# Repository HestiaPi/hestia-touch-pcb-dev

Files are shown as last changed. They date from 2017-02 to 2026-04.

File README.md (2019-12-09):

# HestiaPi Touch

HestiaPi Touch

HestiaPi Touch is a completely open source smart thermostat for your home. With it, you can monitor your home’s temperature, relative humidity, and atmospheric pressure. You can also control your heating, ventilation, air conditioning, hot water, and more from anywhere you have an Internet connection. 

You can do all this securely and with confidence your private data stays private. 

HestiaPi Touch is compatible with many devices and home automation systems and can serve as a central point of control that ties them all together in your home.

For **HestiaPi Touch ONE** select the "ONE" folder above.

# Useful links

* [Main website](https://hestiapi.com/)
* [Documentation & Getting Started Guides](https://github.com/HestiaPi/hestia-touch-openhab/wiki)
* [Community forum](https://community.hestiapi.com/)
* [Code](https://github.com/HestiaPi/hestia-touch-openhab)
* [Electronics (this repo)](https://github.com/HestiaPi/hestia-touch-pcb-dev)
* [3D Case](https://github.com/HestiaPi/hestia-touch-case)

# Support us

HestiaPi is and will always be open source and open hardware. 

Please consider supporting us through our [crowdfunding campaign](https://www.crowdsupply.com/makeopenstuff/hestiapi-touch).

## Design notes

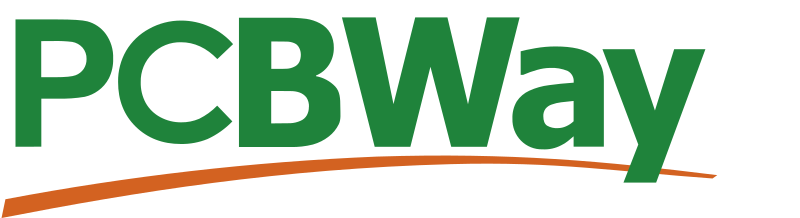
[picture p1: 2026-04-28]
HestiaPi-ONE/KiCAD/PCBWay.bmp

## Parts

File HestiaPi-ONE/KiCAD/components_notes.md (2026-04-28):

# General Notes

- The prices listed here do not include tax nor shipping
- The prices are a snapshot in time. The prices will change over time
- Use alternative components at our own risk. They might work, they might not
- Approximate total cost of for one complete unit (3 relays, US power supply)
  - Components (excluding tax + shipping): $179
  - Tax (varies by jursidiction): $18
  - Shipping: $20
  - Doesn't include a 3D printed case or the solder you'll need to assemble it
  - You'll have parts left over as some are one available in a pack
- Ordering in bulk saves a lot of money (per unit)
  - One project member does this and makes them availalbe for sale
  - https://www.tindie.com/stores/eternalsunshine/

# Switch

- PB400EEQX 3A, 30V DC
  - https://www.mouser.com/ProductDetail/E-Switch/PB400EEQX?qs=f9yNj16SXrL0W%252BH3qwHSkQ%3D%3D
  - https://www.mouser.com/datasheet/2/140/PB400EEQX-3455649.pdf
  - 11mm stem, 11mm body, 2.9mm further to the center of the rear pins
  - $2.10

# Solid state relays

- Panasonic AQG22205
- https://www.mouser.com/ProductDetail/Panasonic-Industrial-Devices/AQG22205?qs=g5ciJ0jwZaGg6SiKVpMkMA%3D%3D
- $4.29

# EU power supply

- HiLink HLK-PM01
- https://www.amazon.com/HLK-PM01-Step-Down-Supply-Intelligent-Household/dp/B01B7GGL6C
- $33.26

# Terminal block

- CUI Devices TB001-500-07BE
- https://www.mouser.com/ProductDetail/490-TB001-500-07BE
- $0.92

# US power supply

- AC 24V to DC 5V buck regulator, 3A or higher
- https://www.amazon.com/gp/product/B07TLL6SN2/?th=1
- $13.31

# 2x20 header pins

- Not needed if you bought a Raspberry Pi with headers pre-installed
- 2x20 headers, 2.54mm pitch
- https://www.mouser.com/ProductDetail/Molex/90131-0140?qs=kEwmkoUtv7QGI7QFyJKDFA%3D%3D
- $3.16

# 2x20 header socket

- 2x20 header socket, 2.54mm picth
- https://www.mouser.com/ProductDetail/Samtec/SSQ-120-01-L-D?qs=%252BZP6%2F%252BtExtDg5xp9qJK50A%3D%3D
- $5.24

# Right angle headers

- https://www.mouser.com/ProductDetail/649-75867-105LF
- https://cdn.amphenol-cs.com/media/wysiwyg/files/documentation/datasheet/boardwiretoboard/bwb_quickie.pdf
- $2.38

Previous pick; it works, but not as well:

- https://www.mouser.com/ProductDetail/Samtec/MTSW-113-07-T-D-100-RA?qs=rU5fayqh%252BE1VVwFKmkPK1g%3D%3D
- https://www.mouser.com/datasheet/2/527/mtsw-2854606.pdf
- $1.61

# Ribbon cable

- https://www.mouser.com/ProductDetail/Samtec/HCMD-13-T-04.00-02-T-G?qs=0lQeLiL1qyYA3A%252BwV50O3A%3D%3D
- https://www.mouser.com/datasheet/2/527/hcmd-2498159.pdf
- $11.93

# LCD touchscreen

- 3.5" touchscreen with XPT2046 touch chip
- https://smile.amazon.com/gp/product/B0BJDTL9J3/
- $17.99

# Temperature & humidity sensor

- BME-280 sensor with breakout board
- https://www.mouser.com/ProductDetail/SparkFun/SEN-13905?qs=t7xnP681wgXFsb5cPFh6iw%3D%3D
- $22.50

# Temp sensor wire

- 4-pin wire with 1x4 header socket connectos
- https://smile.amazon.com/dp/B0789F523N
- $7.99 (that's the price for a 10 pack)

# PCB

- Fabricated by a vendor of your choice
- [OSH Park](https://oshpark.com/) allows ordering just 3 boards, most others have a minimum of 5+
- $50.10 (that's the price for 3 boards, which is the minimum)

# SD Card

- Nearly any micro SD card should do, the 16GB ones seem to be cheapest right now
- $8

# Raspberry Pi Zero 2

- https://www.mouser.com/ProductDetail/Raspberry-Pi/SC0020?qs=rQFj71Wb1eUf2LwSpZJWqw%3D%3D
- $15

# Nuts & bolts

- M2.5 nuts and M2.5x8mm bolts
- https://www.mcmaster.com/90592A006/
  - 1.50 (pack of 100)
- https://www.mcmaster.com/92000A105/
  - $5.17 (pack of 100)

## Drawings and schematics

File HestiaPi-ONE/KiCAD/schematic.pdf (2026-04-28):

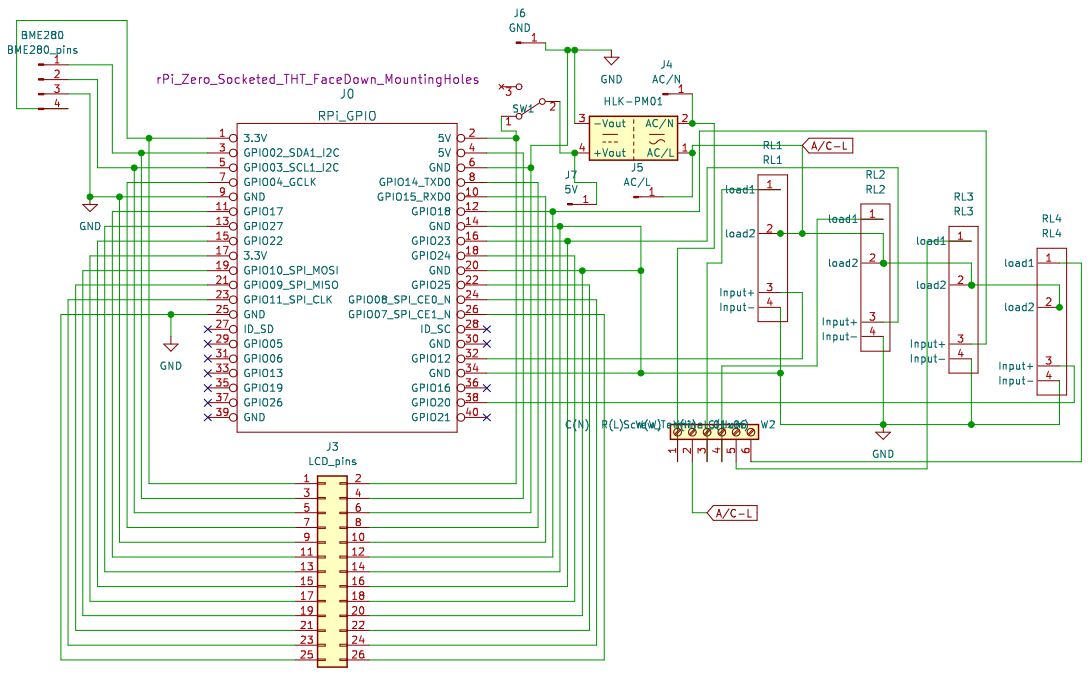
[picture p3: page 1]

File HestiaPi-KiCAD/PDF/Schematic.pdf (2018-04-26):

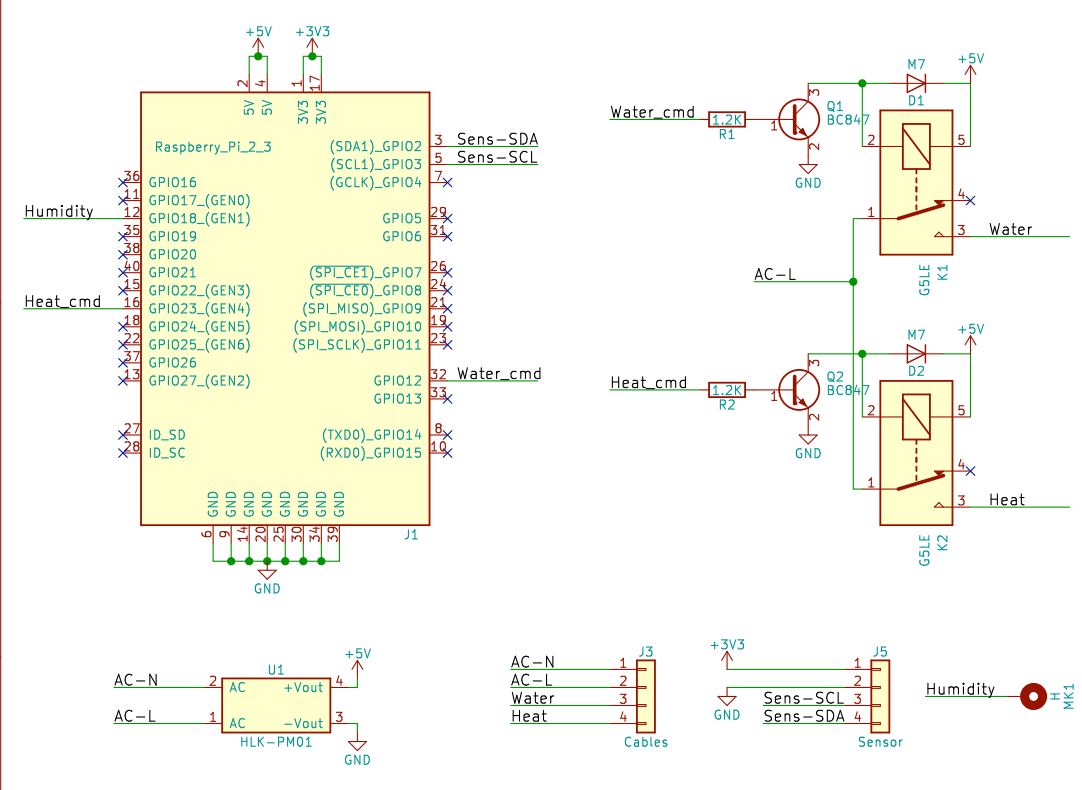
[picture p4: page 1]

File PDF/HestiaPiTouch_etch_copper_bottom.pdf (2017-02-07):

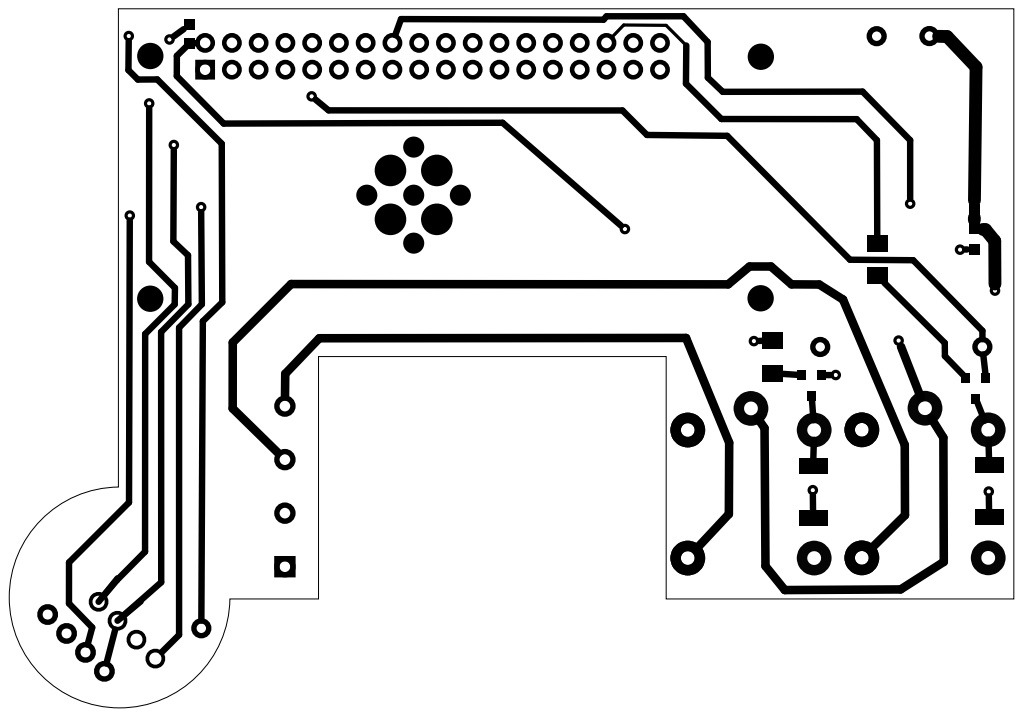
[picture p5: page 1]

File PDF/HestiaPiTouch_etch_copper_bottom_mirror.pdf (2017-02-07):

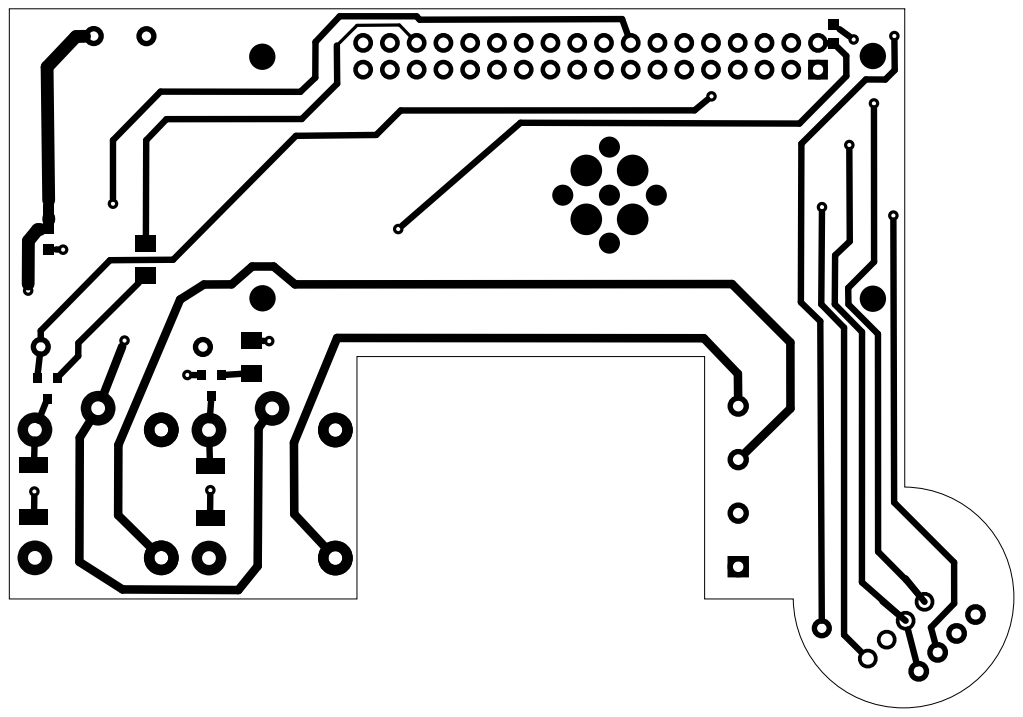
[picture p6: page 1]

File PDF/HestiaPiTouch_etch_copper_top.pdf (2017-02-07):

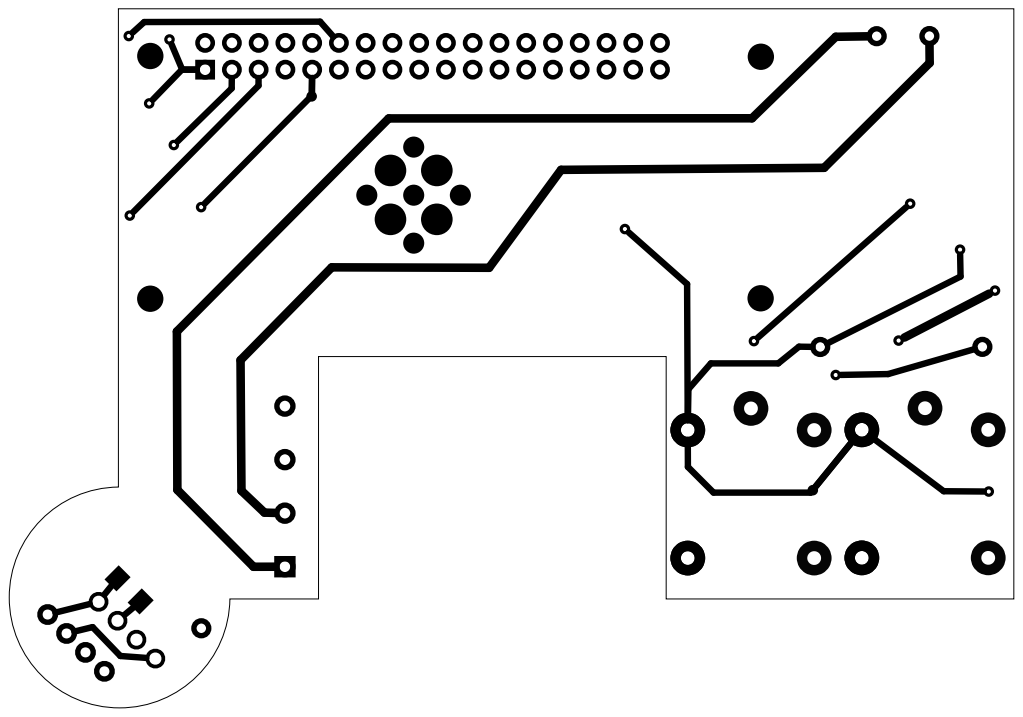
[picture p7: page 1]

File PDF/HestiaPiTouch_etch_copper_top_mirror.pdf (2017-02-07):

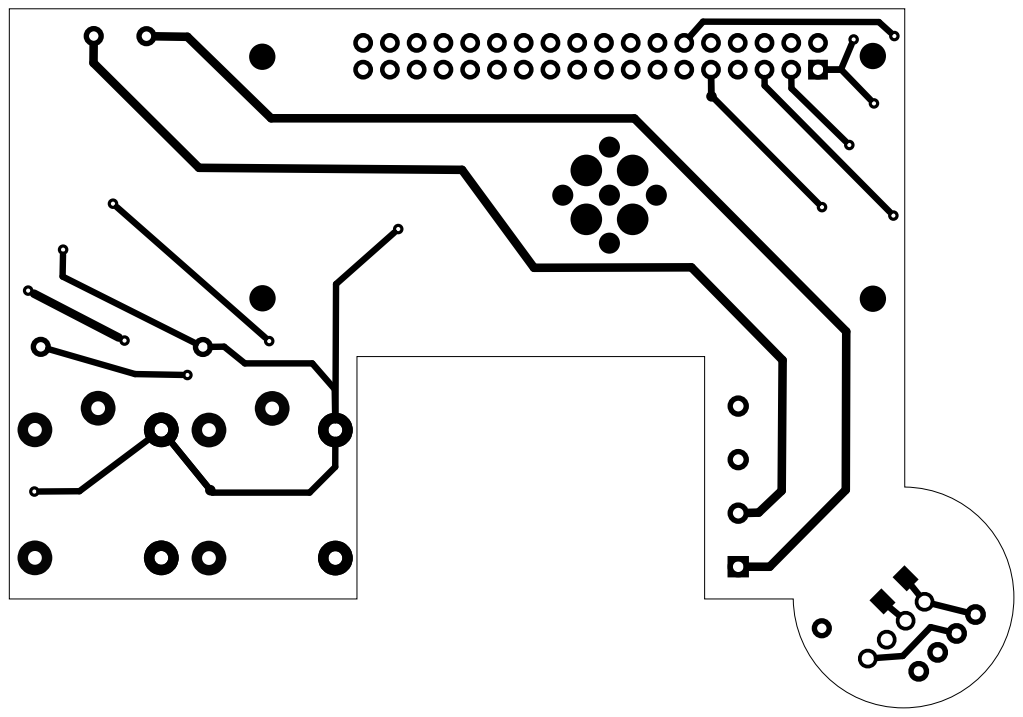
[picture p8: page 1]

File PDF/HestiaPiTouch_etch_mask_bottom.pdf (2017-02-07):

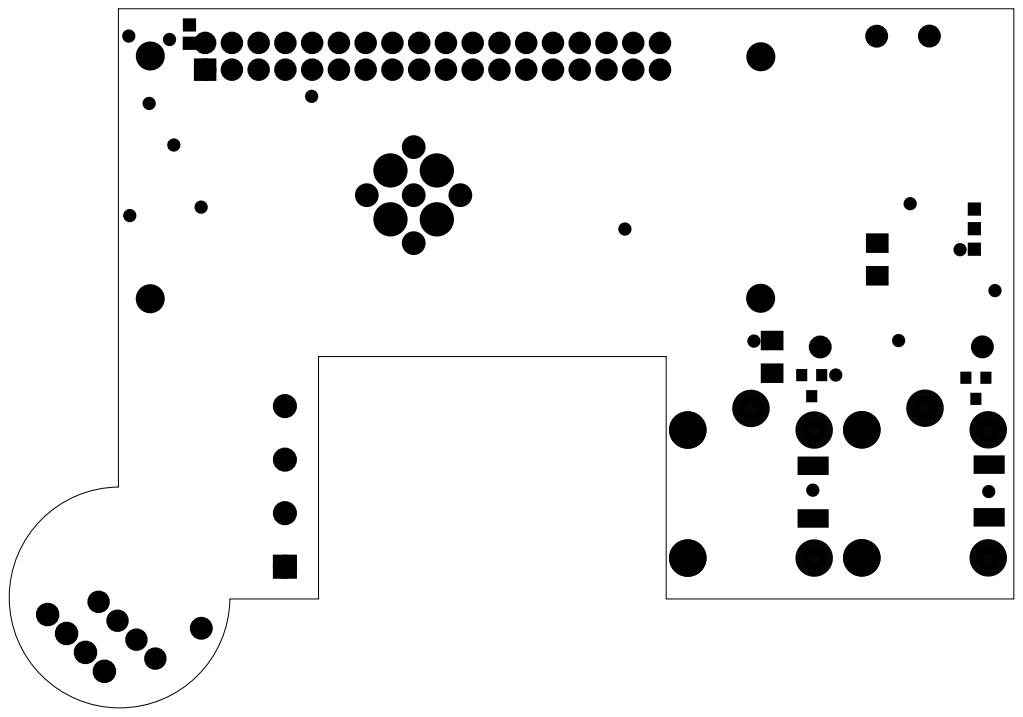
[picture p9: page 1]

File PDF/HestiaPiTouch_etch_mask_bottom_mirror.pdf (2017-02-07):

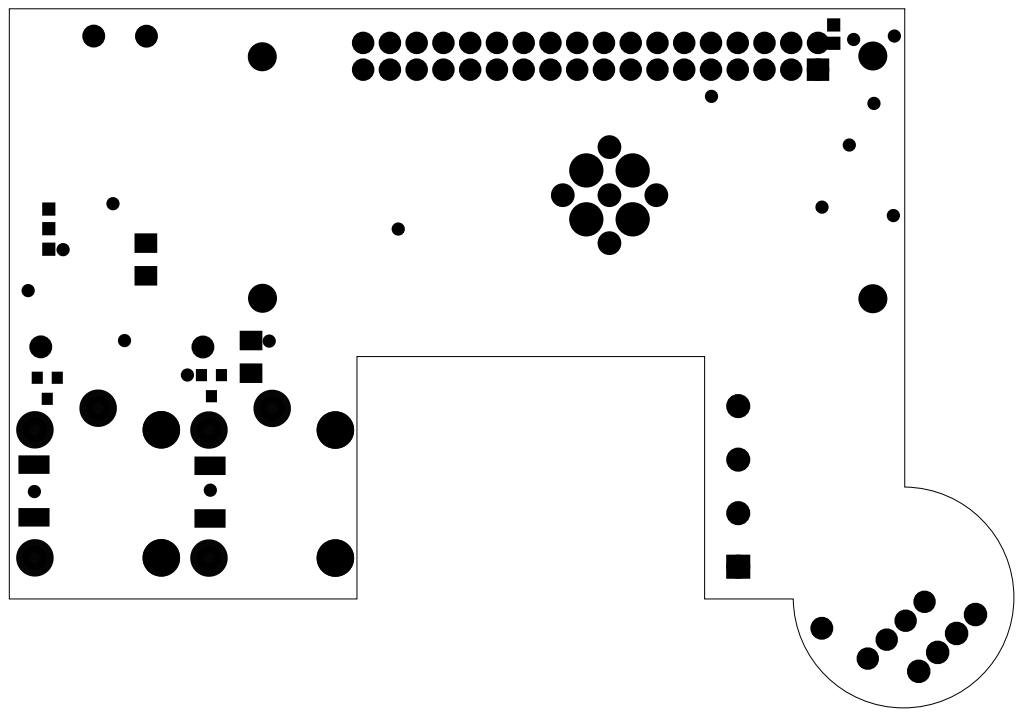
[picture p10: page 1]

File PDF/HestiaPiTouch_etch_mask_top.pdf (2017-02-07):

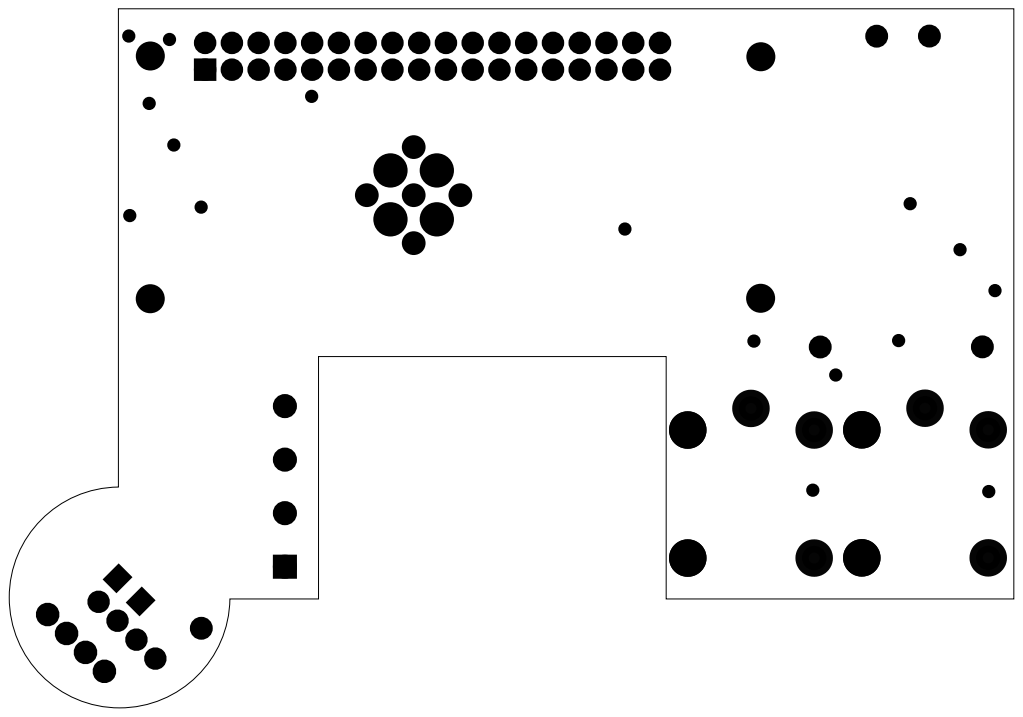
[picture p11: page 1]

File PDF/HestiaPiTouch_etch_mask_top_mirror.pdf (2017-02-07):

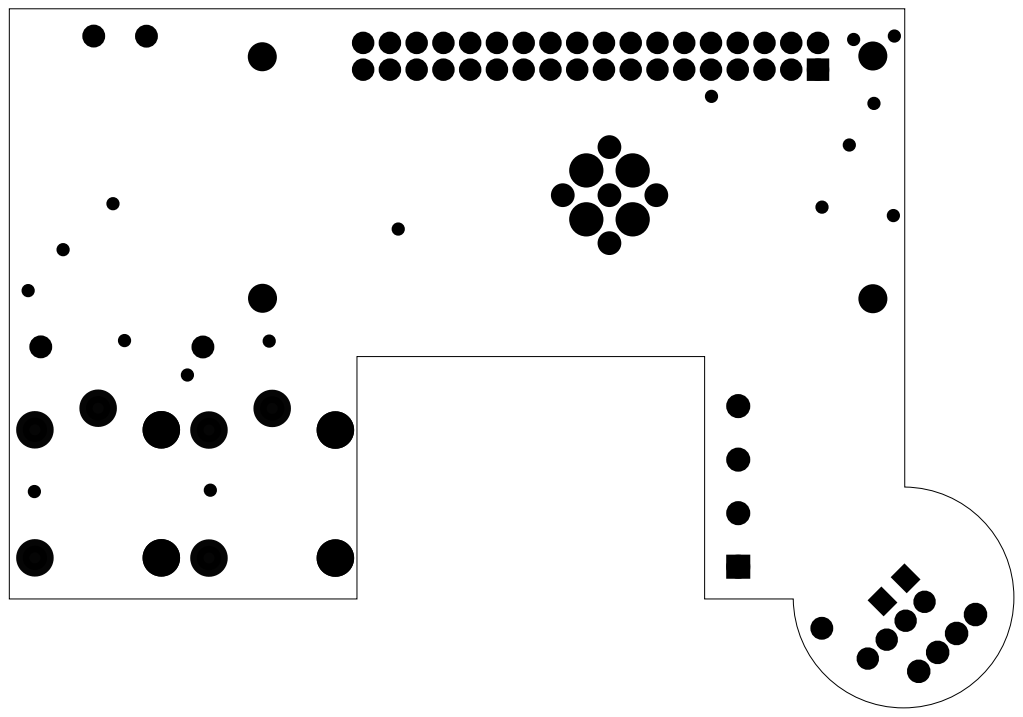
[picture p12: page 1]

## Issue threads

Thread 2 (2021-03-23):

Board outline file for One circuit board

sorvis, 2021-03-23:
Hello,

I tried uploading the Gerbal zip for the One board to oshpark, but it complains "I can't find a board outline file. "

https://oshpark.com/uploads/Jsue3I1o

Would it be possible to add that missing file or perhaps the kicad project? I noticed that the kicad project file works with their software for the other board.

Thank you

gulliverrr, 2021-03-23:
This is not done via KiCAD. I think Fritzing names ones of the needed layers with a different extension.
My suggestion would be to download the zip file, extract it, rename ONE_contour.gml to ONE_contour.GKO (or ONE_contour.gko), re-zip it and try uploading again.
Please report here if it worked

sorvis, 2021-03-23:
Thank you for the quick reply @gulliverrr  I renamed it to ONE_contour.GKO  and it did work just fine!

gulliverrr, 2021-03-23:
Just to mention... I think this difference of Fritzing is not blocking all PCB houses. Some don't complain and process the zip file fine. Since that repository commit, we have moved far from Fritzing as this was our first beginner tool that got us into PCB design.
Glad you got it working

sorvis, 2021-03-23:
Curious if that's an older file that you all created are the newer files in another repository? It looks like the ONE folder was the most recent in this repro.

gulliverrr, 2021-03-24:
No, that would be the latest `released` version. As this project is always progressing, yes there are modifications pending to be either tested or accompanied by the rest of the code, casing, electronics and/or documentation. You are using the right file, for now.

Closed 2021-03-23.

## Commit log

2018-02-10 Initial release KiCAD
    First release of HestiaPi Touch KiCAD project.
    [HestiaPi-KiCAD.kicad_pcb, HestiaPi-KiCAD.sch, Prove.kicad_pcb]
2018-02-10 Clean
    Deleted an useless file
    [Prove.kicad_pcb]
2018-02-11 Gerbers and PDF
    Various gerber files and PDF print added
    [HestiaPi-KiCAD.csv, HestiaPi-KiCAD.dsn, HestiaPi-KiCAD.kicad_pcb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]
2018-02-11 RS-274 gerber file
    RS-274 gerber file added to gerber/Plot folder
    [HestiaPi-KiCAD-B.CrtYd.gbr, HestiaPi-KiCAD-B.Cu.gbr, HestiaPi-KiCAD-B.Fab.gbr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]
2018-02-11 Refined position of nets
    [HestiaPi-KiCAD-B.CrtYd.gbr, HestiaPi-KiCAD-B.Cu.gbr, HestiaPi-KiCAD-B.Fab.gbr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]
2018-02-11 Clean gerber files
    Only RS-274x gerber as needed
    [HestiaPi-KiCAD-B.CrtYd.gbr, HestiaPi-KiCAD-B.Cu.gbl, HestiaPi-KiCAD-B.Fab.gbr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]
2018-03-12 1206 reistor, no jmp, holes
    Modified BJT resistors to bigger 1206 format
    Deleted the COMMON line selector
    Holes under CPU are now the correct size
    [HestiaPi-KiCAD-B.Cu.gbl, HestiaPi-KiCAD-B.Mask.gbs, HestiaPi-KiCAD-B.Paste.gbp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]
2019-12-09 Gerber file for HestiaPi Touch ONE
2019-12-09 Added Fritzing source file
    Fritzing 0.9.3 used
    [ONE.fzz]
2025-09-04 feat: Added v2.5 version of the KiCAD model
    [HestiaPiOneUniversal-B_Cu.gbr, HestiaPiOneUniversal-B_Mask.gbr, HestiaPiOneUniversal-B_Paste.gbr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]
2025-09-08 Added PDF of the schematic
2026-04-27 Version 2.54 of the PCB design (warning: has errors)
    [HestiaPiOneUniversal-B_Cu.gbr, HestiaPiOneUniversal-B_Mask.gbr, HestiaPiOneUniversal-B_Paste.gbr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]
2026-04-27 Version 2.55 of the PCB design (warning: has errors)
    [HestiaPiOneUniversal-B_Cu.gbr, HestiaPiOneUniversal-B_Mask.gbr, HestiaPiOneUniversal-B_Paste.gbr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]
2026-04-27 Version 2.56 of the PCB design (warning: not fully tested)
    [HestiaPiOneUniversal-B_Cu.gbr, HestiaPiOneUniversal-B_Mask.gbr, HestiaPiOneUniversal-B_Paste.gbr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]
